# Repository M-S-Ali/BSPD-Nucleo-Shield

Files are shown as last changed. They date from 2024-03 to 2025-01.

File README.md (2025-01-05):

# BSPD-Nucleo-Shield
Modern vehicles use an accelerator pedal to control the engine’s throttle, which regulates power output. Traditionally, this was achieved through complex mechanical linkages. However, relying solely on the accelerator pedal is not the most efficient way to determine engine power, as other factors like fuel injection and combustion also play a critical role. 

To address this, modern vehicles use **throttle-by-wire systems**, where the accelerator pedal sends electronic signals to a vehicle control unit (VCU). The VCU processes these signals along with other engine parameters to optimize power output. While this approach improves efficiency and performance, it introduces concerns such as potential wire disconnections or data transmission errors. 

In high-performance applications, like racing, safety mechanisms such as the **Brake System Plausibility Device (BSPD)** are used to mitigate risks by cutting off engine power if a fault is detected.

This project focuses on designing an **enhanced throttle-by-wire system** with integrated BSPD functionality. The system is implemented using an **STM32 Nucleo board**, programmed through **MATLAB Simulink**, and employs **fuzzy logic** for intelligent control. A custom-designed **PCB shield** ensures seamless integration with the hardware for practical implementation.

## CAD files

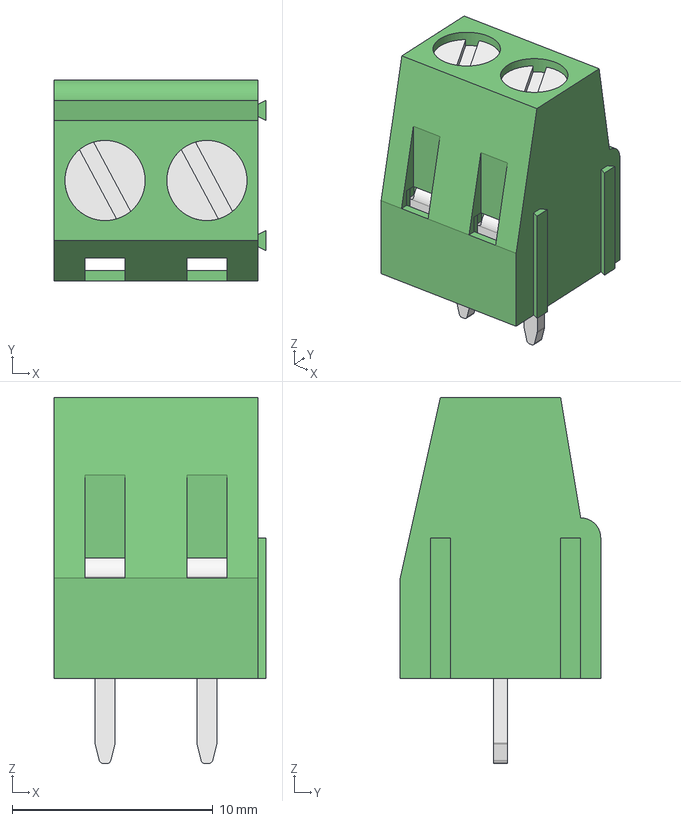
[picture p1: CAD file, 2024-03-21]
3D_Models/2er Terminal Block.step
10.6 x 10.0 x 18.2 mm
Pin (1) (19)
Tornillo (1) (19)
Cubo interno (1) (19)
Pin (1) (1) (18)
Tornillo (1) (1) (18)
Cubo interno (1) (1) (18)
Pin (1) (11)
Tornillo (1) (11)
Cubo interno (1) (11)
Pin (1) (1) (10)
Tornillo (1) (1) (10)
Cubo interno (1) (1) (10)

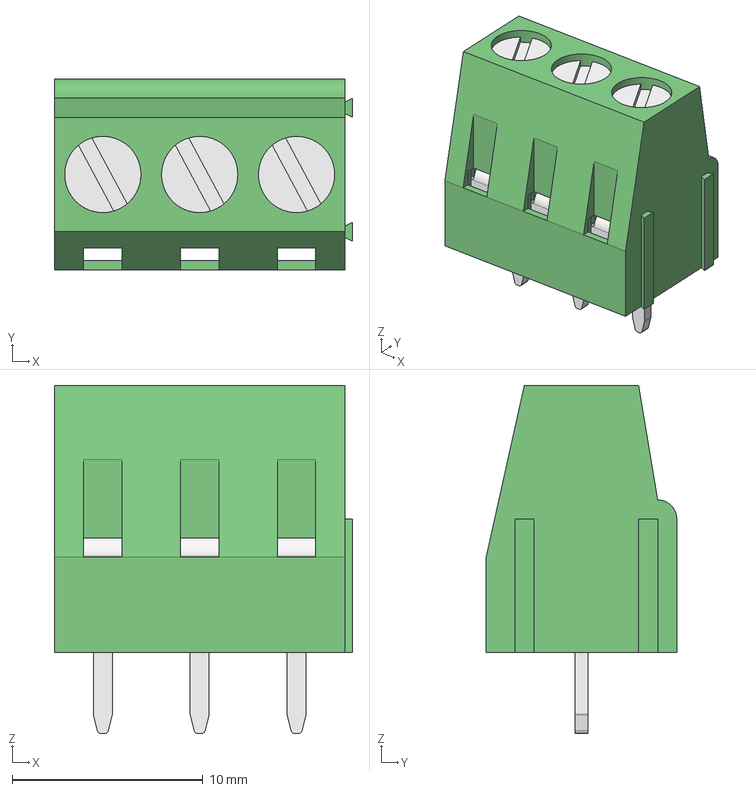
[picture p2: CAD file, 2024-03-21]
3D_Models/3er Terminal Block.step
15.6 x 10.0 x 18.2 mm
Pin (1) (19) (1)
Tornillo (1) (19) (1)
Cubo interno (1) (19) (1)
Pin (1) (1) (18) (1)
Tornillo (1) (1) (18) (1)
Cubo interno (1) (1) (18) (1)
Pin (1) (11) (1)
Tornillo (1) (11) (1)
Cubo interno (1) (11) (1)
Pin (1) (1) (10) (1)
Tornillo (1) (1) (10) (1)
Cubo interno (1) (1) (10) (1)
Pin (1) (17)
Tornillo (1) (17)
Cubo interno (1) (17)
Pin (1) (1) (16)
Tornillo (1) (1) (16)
Cubo interno (1) (1) (16)

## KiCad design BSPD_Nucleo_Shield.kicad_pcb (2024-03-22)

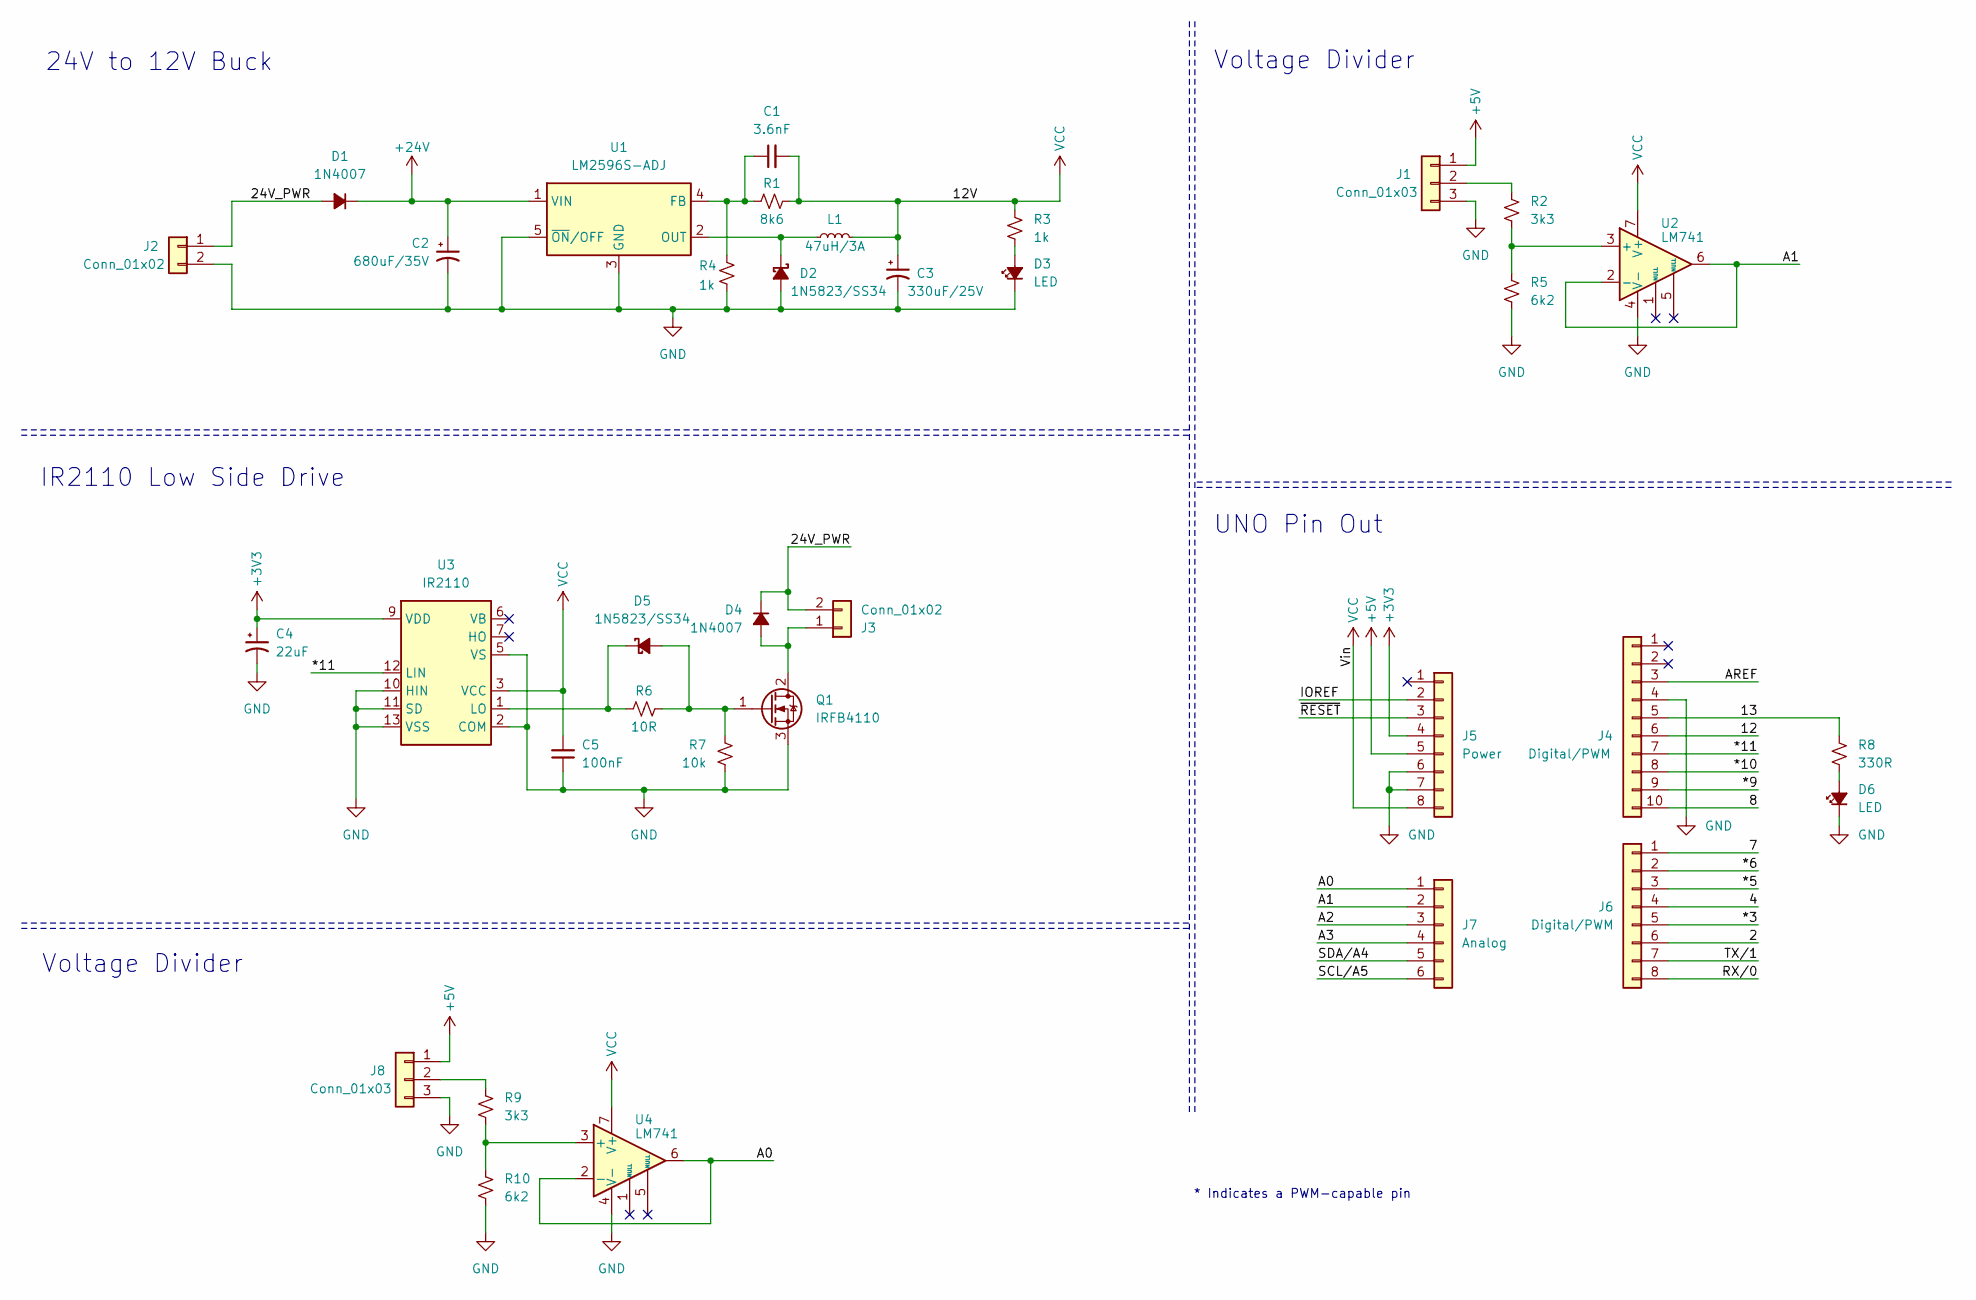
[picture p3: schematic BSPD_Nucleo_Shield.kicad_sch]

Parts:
C1: 3.6nF; C_Disc_D3.0mm_W2.0mm_P2.50mm
C2: 680uF/35V; CP_Radial_D10.0mm_P5.00mm
C3: 330uF/25V; CP_Radial_D8.0mm_P3.50mm
C4: 22uF; CP_Radial_D5.0mm_P2.00mm
C5: 100nF; C_Disc_D3.0mm_W2.0mm_P2.50mm
D1, D4: 1N4007; D_DO-41_SOD81_P10.16mm_Horizontal
D2, D5: 1N5823/SS34; D_SMA_Handsoldering
D3, D6: LED; LED_D3.0mm
J1, J8: Conn_01x03; TerminalBlock_bornier-3_P5.08mm
J2, J3: Conn_01x02; TerminalBlock_bornier-2_P5.08mm
J4: Digital/PWM; PinHeader_1x10_P2.54mm_Vertical
J5: Power; PinHeader_1x08_P2.54mm_Vertical
J6: Digital/PWM; PinHeader_1x08_P2.54mm_Vertical
J7: Analog; PinHeader_1x06_P2.54mm_Vertical
L1: 47uH/3A; L_12x12mm_H8mm
Q1: IRFB4110; TO-220-3_Vertical
R1: 8k6; R_Axial_DIN0207_L6.3mm_D2.5mm_P10.16mm_Horizontal
R2, R9: 3k3; R_Axial_DIN0207_L6.3mm_D2.5mm_P10.16mm_Horizontal
R3, R4: 1k; R_Axial_DIN0207_L6.3mm_D2.5mm_P10.16mm_Horizontal
R5, R10: 6k2; R_Axial_DIN0207_L6.3mm_D2.5mm_P10.16mm_Horizontal
R6: 10R; R_Axial_DIN0207_L6.3mm_D2.5mm_P10.16mm_Horizontal
R7: 10k; R_Axial_DIN0207_L6.3mm_D2.5mm_P10.16mm_Horizontal
R8: 330R; R_Axial_DIN0207_L6.3mm_D2.5mm_P10.16mm_Horizontal
U1: LM2596S-ADJ; TO-263-5_TabPin3
U2, U4: LM741; DIP-8_W7.62mm_LongPads
U3: IR2110; DIP-14_W7.62mm_LongPads

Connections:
+3V3: C4.1, J5.4, U3.9 (VDD)
+5V: J1.1, J5.5, J8.1
+24V: C2.1, D1.1 (K), U1.1 (VIN)
/2: J6.6
/4: J6.4
/7: J6.1
/8: J4.10
/12: J4.6
/13: J4.5, R8.1
/24V_PWR: D1.2 (A), D4.1 (K), J2.1, J3.2
/*3: J6.5
/*5: J6.3
/*6: J6.2
/*9: J4.9
/*10: J4.8
/*11: J4.7, U3.12 (LIN)
/A0: J7.1, U4.2 (-), U4.6
/A1: J7.2, U2.2 (-), U2.6
/A2: J7.3
/A3: J7.4
/AREF: J4.3
/IOREF: J5.2
/RX/0: J6.8
/SCL/A5: J7.6
/SDA/A4: J7.5
/TX/1: J6.7
/~RESET: J5.3
GND: C2.2, C3.2, C4.2, C5.1, D2.2 (A), D3.1 (K), D6.1 (K), J1.3, J2.2, J4.4, J5.6, J5.7, J8.3, Q1.3 (S), R4.2, R5.2, R7.2, R10.2, U1.3 (GND), U1.5 (~ON/OFF), U2.4 (V-), U3.2 (COM), U3.5 (VS), U3.10 (HIN), U3.11 (SD), U3.13 (VSS), U4.4 (V-)
unnamed: D2.1 (K), L1.1, U1.2 (OUT)
unnamed: D3.2 (A), R3.2
unnamed: D4.2 (A), J3.1, Q1.2 (D)
unnamed: D5.2 (A), Q1.1 (G), R6.2, R7.1
unnamed: D5.1 (K), R6.1, U3.1 (LO)
unnamed: D6.2 (A), R8.2
unnamed: J1.2, R2.1
unnamed: J8.2, R9.1
unnamed: C1.1, R1.1, R4.1, U1.4 (FB)
unnamed: R2.2, R5.1, U2.3 (+)
unnamed: R9.2, R10.1, U4.3 (+)
VCC: C1.2, C3.1, C5.2, J5.8, L1.2, R1.2, R3.1, U2.7 (V+), U3.3 (VCC), U4.7 (V+)

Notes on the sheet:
Voltage Divider
IR2110 Low Side Drive
* Indicates a PWM-capable pin
24V to 12V Buck
UNO Pin Out

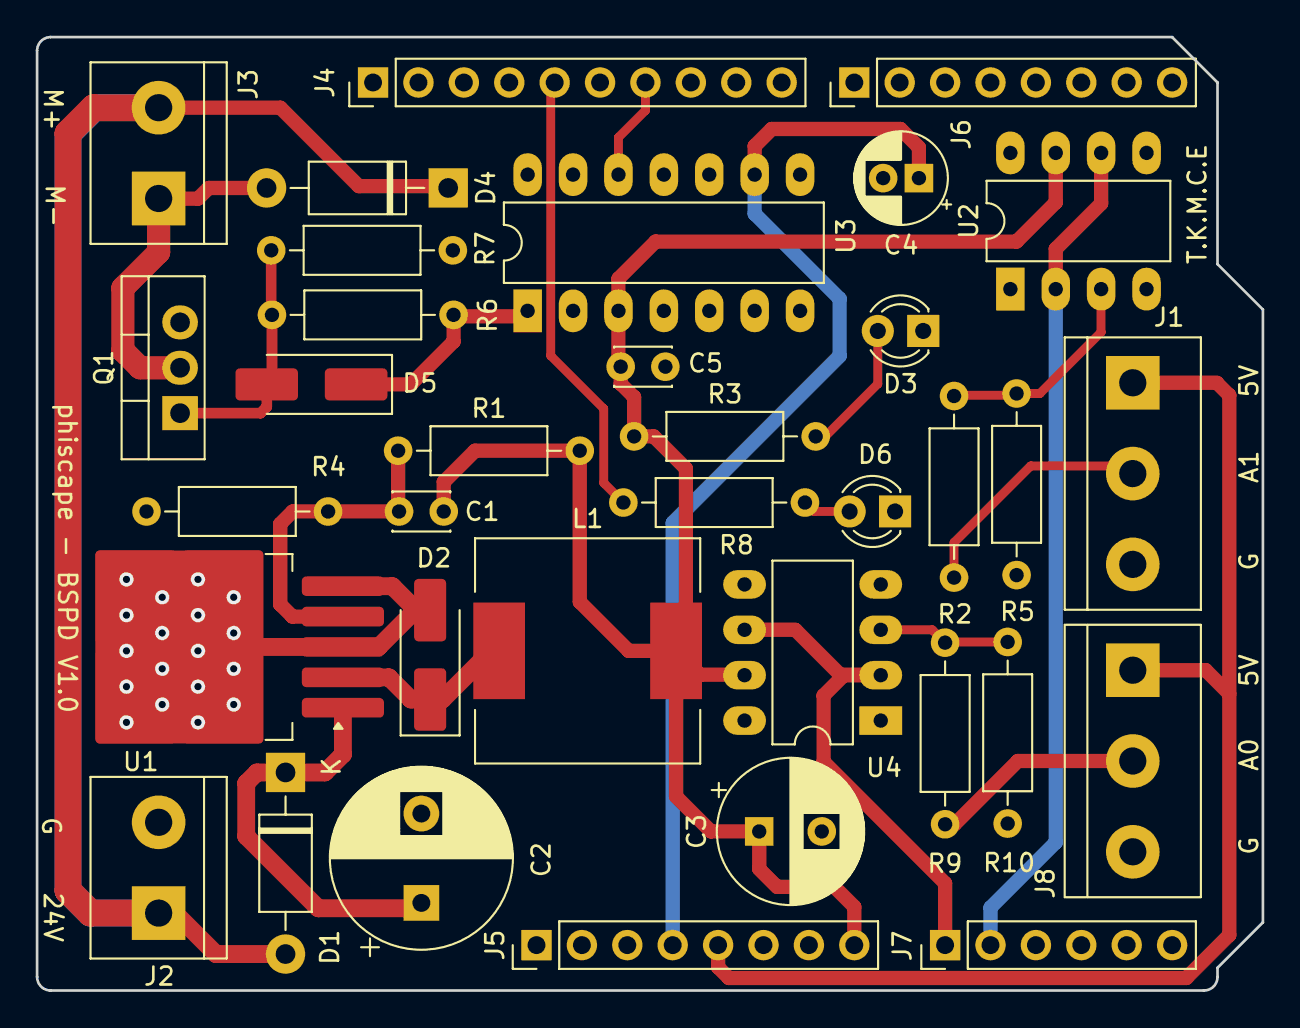
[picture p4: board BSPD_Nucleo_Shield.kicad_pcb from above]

Board: 2 copper layers, 68.6 x 53.3 mm, 35 parts (0 on the bottom side), 21 nets.

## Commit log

2024-03-21 initial upload
    [2er Terminal Block.step, 3er Terminal Block.step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]
2024-03-21 updated to kicad8.0.1
    [BSPD_Nucleo_Shield.kicad_pcb, BSPD_Nucleo_Shield.kicad_sch]
2024-03-22 v1.0 released
    placed order for 5 from lion circuits
    [BSPD_Nucleo_Shield-B_Cu.gbl, BSPD_Nucleo_Shield-B_Mask.gbs, BSPD_Nucleo_Shield-B_Silkscreen.gbo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]
